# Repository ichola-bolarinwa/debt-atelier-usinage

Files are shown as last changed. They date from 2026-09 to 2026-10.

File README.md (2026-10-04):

# DEBT — Dossier d'exécution BT d'un atelier d'usinage

Projet personnel mené seul par Ichola BOLARINWA, étudiant ingénieur à l'ESIGELEC, dominante Énergie et Développement Durable.

## Objet

Produire, comme le ferait un bureau d'études électricité, le dossier d'exécution de l'installation basse tension d'un atelier d'usinage de PME implanté dans l'agglomération de Rouen : raccordement au réseau public basse tension (segment C4, 36 à 250 kVA), schéma de liaison à la terre TT.

## Nature du projet

Étude de cas fictive. Le site, l'entreprise et le programme de machines sont inventés ; chaque donnée technique provient d'une source réelle citée (fiche constructeur, guide technique, texte réglementaire). Aucun client réel n'est impliqué. Le dossier n'a été vérifié par aucun organisme de contrôle.

## Méthode

Chaque grandeur est calculée à la main, puis vérifiée sous XLPro4 Calcul 400 (Legrand). Les écarts entre calcul manuel et logiciel sont expliqués. Chaque hypothèse de dimensionnement est écrite et justifiée dans le cahier des charges.

## Aperçu : plan d'implantation (en cours)

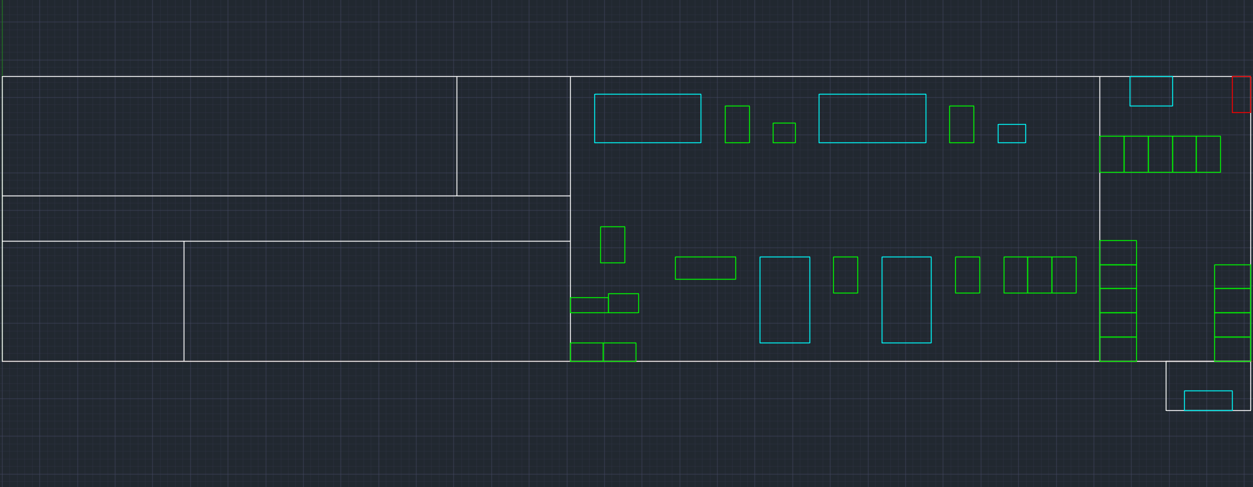
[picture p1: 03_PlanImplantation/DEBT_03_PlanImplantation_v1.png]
Plan d'implantation, état d'avancement


Capture d'avancement du jalon J3.6 : enveloppe du bâtiment, cloisons et implantation des équipements de l'atelier (deux tours CN, deux centres d'usinage, perceuse, postes de préréglage et de contrôle, stockages). Plan non coté, sans échelle ni cartouche ; la version PDF à l'échelle 1:100 remplacera cette image à la clôture du jalon.

Fichier source : [`DEBT_03_PlanImplantation_v1.dwg`](03_PlanImplantation/DEBT_03_PlanImplantation_v1.dwg)

## Livrables

| N° | Livrable | Outil | Dossier | État |
|---|---|---|---|---|
| 00 | Cahier des charges | Claude Docs, export PDF | `00_CahierDesCharges` | Terminé (v1.1) |
| 01 | Bilan de puissance | Excel | `01_BilanPuissance` | Terminé (v4) |
| 02 | Architecture de distribution | Excel, texte | `02_Architecture` | À faire |
| 03 | Plan de masse et d'implantation | AutoCAD | `03_PlanImplantation` | En cours (v1) |
| 04 | Schéma unifilaire | QElectroTech | `04_SchemaUnifilaire` | À faire |
| 05 | Note de calcul manuelle | Excel | `05_NoteCalculManuelle` | À faire |
| 06 | Note de calcul logicielle | XLPro4 Calcul 400 | `06_NoteCalculLogicielle` | À faire |
| 07 | Nomenclature chiffrée | Excel | `07_Nomenclature` | À faire |
| 08 | Synthèse | Texte, export PDF | `08_Synthese` | À faire |

## Avancement

| Jalon | Résultat attendu | État |
|---|---|---|
| J1 | Hypothèses de base validées, cahier des charges v1.0 | Terminé |
| J2 | Machines choisies, bilan de puissance | Terminé |
| J3 | Architecture, plan d'implantation, premier schéma unifilaire | En cours |
| J4 | Note de calcul manuelle complète | À faire |
| J5 | Vérification sous XLPro4 Calcul et analyse des écarts | À faire |
| J6 | Nomenclature chiffrée, synthèse, dossier final | À faire |

## Nommage des fichiers

`DEBT_[NumLivrable]_[Nom]_v[X].[ext]` — exemple : `DEBT_04_SchemaUnifilaire_v2.qet`

## Sources

Voir `SOURCES.md`. Les documents de référence ne sont pas redistribués dans ce dépôt : ils sont protégés par le droit d'auteur de leurs éditeurs.

## Projets liés

Ce dossier est le premier de trois projets. L'avant-projet photovoltaïque (APV) étudiera une centrale en toiture du même bâtiment ; l'outil d'analyse de performance photovoltaïque (MPV) viendra ensuite.

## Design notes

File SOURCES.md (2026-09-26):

# Sources

Documents de référence utilisés pour le DEBT. Titres relevés sur la page de garde ou la page de publication de chaque document. Les documents eux-mêmes ne sont pas redistribués.

## Guides techniques

| Document | Éditeur | Usage |
|---|---|---|
| Guide de l'installation électrique 2017 — Normes internationales CEI et nationales françaises NF | Schneider Electric | Méthodes de calcul : facteurs ku et ks (chapitre A, § 4.3, p. A23 à A26), ratios d'éclairage (fig. A9), schéma TT (chapitre E), sections, chutes de tension, courants de court-circuit, sélectivité |
| NF C 15-100 – Révision 23 août 2024 – Points clés & solutions Legrand, réf. MM224003 (août 2026) | Legrand | Repères généraux d'installation ; orienté logement |
| L'aménagement des bureaux — Principales données ergonomiques, fiche pratique de sécurité ED 23, 2e édition, avril 2007 | INRS | Surface minimale des bureaux : 10 m² utiles par personne, d'après la NF X 35-102 |

## Fiches et catalogues des équipements

| Document | Éditeur | Usage |
|---|---|---|
| Lynx 2100·2600, catalogue, ver. EN 260615 | DN Solutions | Tour Lynx 2100LA : puissance de raccordement 24,21 kVA (p. 32), encombrement (p. 15) |
| DNM 4000, catalogue, ver. EN 260615 | DN Solutions | Centre d'usinage DNM 4000 : puissance de raccordement 29,5 kVA, encombrement (p. 13) |
| Fiche produit OPTIdrill B 34H, article 3020333 | Stürmer Maschinen (Optimum) | Perceuse : moteur 1,50 / 2,20 kW, 400 V |
| OPTIsaw S 275N (revendeurs, source secondaire) | Optimum | Scie : moteur 1,1 kW, pompe 90 W — à confirmer par la fiche du constructeur |
| W22 Three-Phase Electric Motor – Technical Catalogue European Market (50025712) | WEG | Moteurs de référence IE3 : rendement, facteur de puissance, courant (p. 34) |
| Brochure G 2-7 / G 7L-15 / G 15L-22 (2935 0869 42) | Atlas Copco | Compresseur G 11 : 11 kW (p. 7) |
| Manuel d'instructions G 7 / G 11 / G 15 (2924 7191 00) | Atlas Copco | Démarrage étoile-triangle, version IEC (p. 58, 80-81) |
| Technical data / accessories – Demag DC-Com chain hoist (203 571 44, 13/12/2019) | Demag | Palan d'une tonne : moteurs (p. 13, 15, 27, 28), cote de crochet 557 mm (p. 32) |
| Air Conditioning Technical Data RXM-R (EEDEN21A) | Daikin | Pompe à chaleur des bureaux : alimentation, fusible (p. 5-6) |
| Notice technique installation-maintenance JM 12 et JM 22 (19/07/2010) | Jetto | Tubes radiants : 65 W, 230 V (p. 2, 6, 7) |
| Zénéo 200 L vertical mural (revendeurs, source secondaire) | Atlantic | Chauffe-eau : 2 200 W — à confirmer par la fiche du constructeur |

## Tarifs

| Document | Éditeur | Usage |
|---|---|---|
| Tarif professionnel de référence 2026/10 | Legrand | Références et prix de l'appareillage |
| Tarif Legrand Cable Management, juillet 2026 (sans page de garde ; date lue dans l'en-tête de colonne) | Legrand | Références et prix du cheminement des câbles |

## Textes réglementaires

| Document | Éditeur | Usage |
|---|---|---|
| Délibération n° 2025-78 du 13 mars 2025 portant décision sur le tarif d'utilisation des réseaux publics d'électricité dans les domaines de tension HTA et BT (TURPE 7 HTA-BT) | Commission de régulation de l'énergie | Structure et formules du tarif d'acheminement |
| Délibération n° 2026-33 du 4 février 2026 portant modification des tarifs d'utilisation des réseaux publics de distribution et transport d'électricité (TURPE 7 HTA-BT et TURPE 7 HTB) | Commission de régulation de l'énergie | Points techniques du TURPE 7 |
| Délibération n° 2026-105 du 21 mai 2026 portant décision sur l'évolution au 1er août 2026 de la grille tarifaire des tarifs d'utilisation des réseaux publics d'électricité dans les domaines de tension HTA et BT et sur l'évolution du paramètre Rf | Commission de régulation de l'énergie | Coefficients au 1er août 2026 : composante de soutirage (p. 27), dépassements (p. 28), gestion et comptage |
| TURPE 7 HTA/BT – Tarifs en vigueur au 1er août 2026 | Enedis | Formule de la composante de soutirage (p. 15), dépassements (p. 16), saisons tarifaires (p. 22) |

## Limites

La norme NF C 15-100 n'est pas consultée directement : elle est payante. Ses règles sont prises dans les guides des fabricants ci-dessus. La norme EN 15011 (ponts roulants), également payante, n'a pas été consultée.

Les valeurs issues de sources secondaires ou d'hypothèses sont listées dans l'onglet Registre du bilan de puissance, à confirmer avant la version finale du dossier.

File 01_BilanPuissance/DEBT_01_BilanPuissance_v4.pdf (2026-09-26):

Projet DEBT : dossier d'exécution basse tension Bilan de puissance Atelier d'usinage de PME — livrable 1, document de lecture | Référence | DEBT_01
| Version | 4
| Date | 26/09/2026
| Jalon | J2 clos
| Auteur | Ichola BOLARINWA

Ce PDF est une mise en page de lecture du classeur DEBT_01_BilanPuissance_v4.xlsx, qui fait foi : toutes les valeurs y sont calculées par des formules visibles. Méthode : guide Schneider Electric 2017, chapitre A, § 4.3 (p. A22 à A26). Les lignes sur fond clair comportent au moins une valeur à confirmer (section 5).

## 1. Récepteurs

S unitaire : puissance apparente d'un récepteur. Pour une puissance utile de moteur, S = P ⁄ (η × cos φ) ; pour une puissance électrique, S = P ⁄ cos φ ; une puissance donnée en kVA est reprise telle quelle.

Tableau 1 — Récepteurs, puissances et facteurs d'utilisation

Repère | Récepteur et modèle | Groupe | Qté | Donnée constructeur
η | cos
φ

S unitaire
(kVA)

S installée
(kVA)

ku

ku

× S
(kVA)

IB

unitaire
(A)

Statut

T1-T2 Tour à commande numérique DN Solutions Lynx 2100LA
(FANUC)
G1 | 2 | 24,21 kVA | — | — | 24,21 | 48,42 | 0,75 | 36,31 | 34,9 | Sourcé
C1-C2 | Centre d'usinage vertical
DN Solutions DNM 4000
G1 | 2 | 29,50 kVA | — | — | 29,50 | 59,00 | 0,75 | 44,25 | 42,6 | Sourcé
P1 | Perceuse à colonne
Optimum OPTIdrill B 34H (2,2 kW, grande vitesse)
G2 | 1 | 2,20 kW (méca.) | 0,870 | 0,79 | 3,20 | 3,20 | 0,75 | 2,40 | 4,6 | Sourcé

Repère | Récepteur et modèle | Groupe | Qté | Donnée constructeur | η | cos φ | S unitaire (kVA) | S installée (kVA) | ku | ku × S (kVA) | IB unitaire (A) | Statut
S1 | Scie à ruban — moteur de lame Optimum OPTIsaw S 275N | G2 | 1 | 1,10 kW (méca.) | 0,841 | 0,79 | 1,66 | 1,66 | 0,75 | 1,24 | 2,4 | À confirmer
S1p | Scie à ruban — pompe d'arrosage Optimum OPTIsaw S 275N | G2 | 1 | 0,09 kW (élec.) | — | 1,00 | 0,09 | 0,09 | 0,75 | 0,07 | 0,1 | À confirmer
K1 | Compresseur d'air à vis (étoile-triangle) Atlas Copco G 11 | G2 | 1 | 11,00 kW (méca.) | 0,912 | 0,83 | 14,53 | 14,53 | 1,00 | 14,53 | 21,0 | À confirmer
PR-L | Pont roulant 1 t — levage
Demag DC-Com 10, palan à chaîne 1 000 kg, mouflage 1/1
G2 | 1 | 2,15 kVA | — | — | 2,15 | 2,15 | 1,00 | 2,15 | 3,1 | Sourcé
PR-C | Pont roulant 1 t — translation chariot Demag E11 (chariot U11) | G2 | 1 | 0,10 kW (élec.) | — | 1,00 | 0,10 | 0,10 | 1,00 | 0,10 | 0,1 | À confirmer
PR-P | Pont roulant 1 t — translation pont Demag E22-C (2, maître et esclave) | G2 | 2 | 0,20 kW (élec.) | — | 1,00 | 0,20 | 0,40 | 1,00 | 0,40 | 0,3 | À confirmer
E-AT | Éclairage atelier
Luminaires LED
G3 | 1 | 5,60 kVA | — | — | 5,60 | 5,60 | 1,00 | 5,60 | 24,3 | Sourcé
E-MG | Éclairage magasin
Luminaires LED
G3 | 1 | 0,70 kVA | — | — | 0,70 | 0,70 | 1,00 | 0,70 | 3,0 | Sourcé
E-CP | Éclairage local compresseur
Luminaires LED
G3 | 1 | 0,14 kVA | — | — | 0,14 | 0,14 | 1,00 | 0,14 | 0,6 | Sourcé
E-BU | Éclairage bureaux
Luminaires LED
G3 | 1 | 1,44 kVA | — | — | 1,44 | 1,44 | 1,00 | 1,44 | 6,3 | Sourcé
E-LS | Éclairage locaux sociaux
Luminaires LED
G3 | 1 | 0,42 kVA | — | — | 0,42 | 0,42 | 1,00 | 0,42 | 1,8 | Sourcé

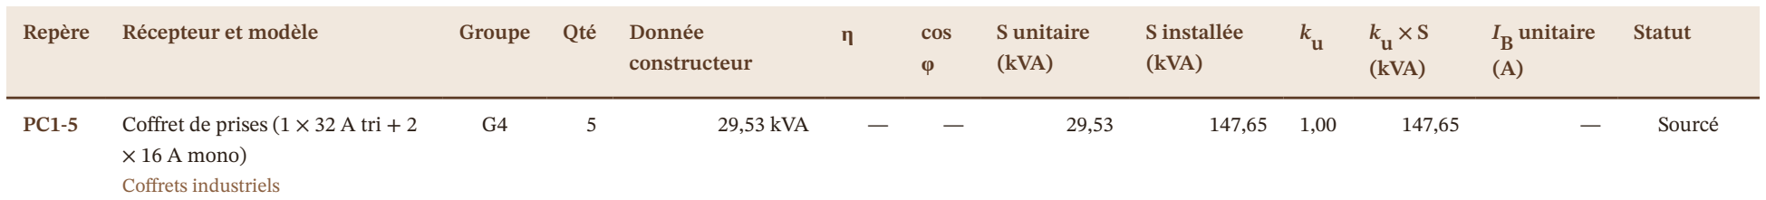
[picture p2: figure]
Repère; Récepteur et modèle; Groupe; Qté; Donnée; constructeur; cos; S unitaire (kVA); S installée (kVA); (kVA); unitaire; Statut; × 16 A mono); Coffrets industriels; 29,53 kVA; Sourcé

PC1-5 | Coffret de prises (1 × 32 A tri + 2
PB | Prises bureautiques
—
G5 | 1 | 1,50 kVA | — | — | 1,50 | 1,50 | 1,00 | 1,50 | 6,5 | Sourcé
CE | Chauffe-eau électrique 200 L
Atlantic Zénéo 200 L vertical mural
G5 | 1 | 2,20 kW (élec.) | — | 1,00 | 2,20 | 2,20 | 1,00 | 2,20 | 9,6 | Sourcé
PAC | Pompe à chaleur air/air bureaux Daikin Perfera FTXM50R + RXM50 | G5 | 1 | 1,45 kW (élec.) | — | 1,00 | 1,45 | 1,45 | 1,00 | 1,45 | 6,3 | À confirmer
TR | Auxiliaires des tubes radiants gaz Jetto Monobloc JM 22 (22 kW gaz) | G5 | 4 | 0,07 kW (élec.) | — | 1,00 | 0,07 | 0,26 | 1,00 | 0,26 | 0,3 | À confirmer
Total | 290,91 | 262,82

## 2. Synthèse par groupe et au TGBT

Tableau 2 — Puissance d'utilisation par groupe : P
u

= k
s

× Σ(ku
× S)
Groupe | Contenu | Σ ku
× S
| | (kVA)

k
s

P
u
(kVA)

IB
(A)

Source du k
s
G1 | Machines à commande numérique (4 circuits) | 80,56 | 0,80 | 64,45 | 93,0 | Fig. A12, p. A25 : tableau de 4 à 5 circuits
G2 | Autres moteurs : perceuse, scie, compresseur, pont roulant (4 circuits) | 20,89 | 0,80 | 16,71 | 24,1 | Fig. A12, p. A25 : tableau de 4 à 5 circuits
G3 | Éclairage | 8,30 | 1,00 | 8,30 | 12,0 | Fig. A13, p. A26 : éclairage
G4 | Coffrets de prises | 147,65 | 0,20 | 29,53 | 42,6 | Fig. A13, p. A26 : prises 0,1 à 0,2, valeur haute (usage industriel)

Groupe | Contenu | Σ ku
× S
| | (kVA)

k
s

P
u
(kVA)

IB
(A)

Source du k
s
G5 | Bureaux, locaux sociaux, chauffage : bureautique, chauffe-eau,
pompe à chaleur, auxiliaires
5,41 | 1,00 | 5,41 | 7,8 | Fig. A13, p. A26 : chauffage et conditionnement d'air ; valeur prudente pour la bureautique

Tableau 3 — Au TGBT

Somme des puissances d'utilisation des groupes | 124,40 kVA

k
s
du TGBT (provisoire, 3 départs supposés ; fig. A12, p. A25) | 0,90
Coefficient d'extension (H13 : aucune extension prévue) | 1,00
Puissance d'utilisation au TGBT | 111,96 kVA
Courant d'emploi au point de livraison | 161,6 A
Marge sous le plafond C4 de 250 kVA | 55,2 %
Contrôle : force motrice d'un atelier d'usinage par ratio (fig. A9, 300 VA/m² × 400 m²) | 120,0 kVA
Contrôle : puissance installée des seules machines à commande numérique | 107,42 kVA

IB =

Pu

3

× U

=

111 963 VA

3

× 400 V

≈ 161,6 A

où P
u

est la puissance d'utilisation au TGBT et U la tension entre phases.

## 3. Puissance à souscrire (TURPE 7, BT > 36 kVA)

Composante de soutirage : CS = b
1

·P
1

+ Σ b
i

·(P
i

− P

i−1) + Σ c
i

·E
i

, avec P
1

≤ P
2

≤ P
3

≤ P
4

et la plage 1 correspondant aux heures pleines de saison haute (Enedis, TURPE 7 HTA/BT au 1er août

2026, p. 15). Le pic de l'atelier tombant en heures pleines toute l'année, les quatre puissances sont égales et seul le terme b 1

·P
1

subsiste.

Tableau 4 — Comparaison des options (coefficients : délibération CRE n° 2026-105, p. 27-28)

Grandeur | Courte utilisation | Longue utilisation
Puissance souscrite, identique sur les quatre plages | 112 kVA | 112 kVA
Énergie annuelle majorante (H12 : 8 h × 5 j × 52 sem., toute en heures pleines) | 232 884 kWh | 232 884 kWh
Composante de soutirage annuelle, cas majorant | 11 916,79 € | 11 979,29 €
Écart longue − courte utilisation | | +62,50 €/an

Conclusion : 112 kVA sur les quatre plages, option courte utilisation. Elle reste la moins chère même dans le cas majorant de H12 ; l'énergie réelle, plus faible, renforce ce choix. Un kVA sous‐ crit en plus coûte 18,15 € par an, une heure de dépassement 12,79 € : une petite marge de souscription vaut mieux que des dépassements.

## 4. Paramètres

Tableau 5 — Surfaces (H5)

Zone | Surface | Source
Atelier | 400 m² | Valeur de programme (H5)
Magasin et expédition | 100 m² | Valeur de programme (H5)
Local compresseur | 20 m² | Valeur de programme (H5)
Bureaux (m² utiles) | 60 m² | INRS ED 23 (2007) : 10 m² par poste × 6 postes (H3, H5)
Locaux sociaux | 60 m² | Valeur de programme (H5)

Tableau 6 — Ratios d'éclairage (H11) et de bureautique

Usage | Ratio | Source
Éclairage — circulation, stockage (150 lx) | 7 VA/m² | Guide Schneider 2017, fig. A9, p. A22-A23 (base fluorescente : majorant pour LED)
Éclairage — gros travaux, atelier (300 lx) | 14 VA/m² | Idem
Éclairage — bureaux (500 lx) | 24 VA/m² | Idem
Force motrice — bureaux (bureautique) | 25 VA/m² | Guide Schneider 2017, fig. A9, p. A23
Contrôle : force motrice atelier d'usinage | 300 VA/m² | Guide Schneider 2017, fig. A9, p. A23 (ordre de grandeur de contrôle)

Coffret de prises type : 1 prise 32 A triphasée et 2 prises 16 A monophasées, soit 29,53 kVA au courant assigné ; 4 coffrets dans l'atelier (un par zone de travail) et 1 au magasin. Calibres normali‐ sés CEI 60309 ; nombre à vérifier sur le plan du J3.

## 5. Sources, justifications et registre

Tableau 7 — Source de chaque donnée et justification du ku

Repère | Source de la donnée | Justification du ku
T1-T2 | Catalogue DN Solutions « Lynx 2100·2600 », ENG E36 260615, p. 32, ligne Power consumption (FANUC). ku : guide Schneider 2017, § 4.3.1, p. A23 | Moteurs en installation industrielle : 0,75 en moyenne (guide Schneider 2017, § 4.3.1, p. A23)
C1-C2 | Catalogue DN Solutions « DNM 4000 », ENG SU E16 260615, p. 13, ligne electric power supply (rated capacity). ku : idem | Idem (§ 4.3.1, p. A23)
P1 | P : fiche Stürmer Maschinen OPTIdrill B 34H, art. 3020333 (1,50 / 2,20 kW, 400 V). η, cos φ : moteur de référence WEG W22 IE3 2,2 kW 4 pôles, carcasse 100L, catalogue WEG 50025712, p. 34 (In = 4,62 A) | Idem (§ 4.3.1, p. A23) ; machine manuelle intermittente
S1 | P : Optimum S 275N, 1,1 kW 400 V (revendeurs : source secondaire). η, cos φ : moteur de référence WEG W22 IE3 1,1 kW 4 pôles, carcasse 90S, catalogue WEG 50025712, p. 34 (In = 2,39 A) | Idem (§ 4.3.1, p. A23)
S1p | P : fiche Optimum S 275N (90 W). cos φ inconnu, pris égal à 1 (sous-estimation négligeable) | Idem (§ 4.3.1, p. A23)

Repère | Source de la donnée | Justification du ku
K1 | P = 11 kW : brochure Atlas Copco G 2-22 (2935 0869 42), p. 7. Démarrage étoile-triangle (version IEC) : manuel Atlas Copco G 7-G 15 (2924 7191 00), p. 58 et 80-81. η, cos φ : moteur de référence WEG W22 IE3 11 kW 2 pôles, catalogue WEG 50025712,
p. 34 (In = 21,0 A). Polarité réelle à lire sur plaque
| | Au-dessus de la moyenne du § 4.3.1 : fonctionnement quasi continu pendant le poste ; 1 retenu par prudence
PR-L | Moteur ZNK 100 A 8/2, grande vitesse 1,10 kW, 40 % ED, In = 3,1 A à 380-415 V, cos φ 0,81 : Demag, Technical data DC-Com (203 571 44, 13/12/2019), p. 13 et 15. S = √3 × 400 × 3,1 | Moteur à pleine charge pendant le levage ; l'intermittence est prise en compte par le ks du groupe
PR-C | Demag 203 571 44, p. 27 : E11, 0,1 / 0,025 kW. cos φ inconnu : S pris égal à P (sous-estimation négligeable) | Idem levage
PR-P | Hypothèse : 2 motoréducteurs E22-C, 0,2 / 0,05 kW, cités comme entraînement de translation (Demag 203 571 44, p. 28). À confirmer par devis de pont | Idem levage
E-AT | Surface H5 × ratio fig. A9 (300 lx). ku = 1 : guide Schneider, p. A23 | Éclairage : ku = 1 (§ 4.3.1, p. A23)
E-MG | Surface H5 × ratio fig. A9 (150 lx) | Idem
E-CP | Surface H5 × ratio fig. A9 (150 lx) | Idem
E-BU | Surface H5 × ratio fig. A9 (500 lx) | Idem
E-LS | Surface H5 × ratio fig. A9, ligne circulation (choix : pas de ligne spécifique) | Idem
PC1-5 | Choix de conception (4 coffrets atelier, 1 magasin), méthode du courant assigné. ks du groupe : fig. A13 | Prises comptées à leur courant assigné (ku = 1) ; la faible utilisation est prise par ks = 0,2 (fig. A13, p. A26)
PB | Surface bureaux × ratio fig. A9 « bureaux » (25 VA/m²) | Ratio de consommation déjà moyenné (fig. A9) : pas de réduction supplémentaire
CE | Fiche Atlantic Zénéo, réf. ED 999 538 (octobre 2015) : 2 200 W, 230 V. Résistif : cos φ = 1, ku = 1 (p. A23) | Résistif, chauffage : ku = 1 (§ 4.3.1, p. A23)
PAC | daikin.eu : capacité de chauffage nominale 5,8 kW, COP 4,00, d'où P = 5,8 ⁄ 4,00. Non dimensionnée par calcul thermique ; cos φ pris égal à 1. À confirmer : puissance absorbée maximale | Chauffage et climatisation : ku = 1 (§ 4.3.1 ; fig. A13)
TR | Fiche Jetto Monobloc (Batiproduits) : 65 W, 230 V. Nombre de tubes provisoire (4) : calcul de déperditions au J6. Impact négligeable | Auxiliaires en service pendant toute la chauffe : ku = 1

Tableau 8 — Registre des sources à confirmer avant la version finale

N° | Élément | Valeur provisoire | Source actuelle | Source à obtenir | Poids sur le bilan
1 | Scie : fiche constructeur | 1,1 kW ; pompe 90 W | Revendeurs Optimum (secondaire) | Fiche ou notice Optimum / Stürmer S 275N (réf. 3300260) | Négligeable

### 2 Compresseur : polarité et courant du

moteur

2 pôles supposés ; 21,0 A
(moteur de référence)

WEG W22 IE3 11 kW 2 p. (primaire, moteur de référence)

Plaque signalétique ou fiche électrique Atlas Copco G 11

Modéré (≈ 14 kVA)

3 | Pont roulant : translation du pont | 2 × 0,2 kW | Demag 203 571 44, p. 28 (usage hors palan)
Devis d'un pont monopoutre 1 t | Négligeable

4 Pont roulant : hauteur de poutre,
chemin de roulement, jeu en partie haute
à déterminer | — | Devis constructeur ; norme EN 15011 (payante)

Conditionne la hauteur
sous charpente (H4)

### 5 Pompe à chaleur : puissance absorbée

maximale

1,45 kW (nominale) ;
fusible maxi 16 A

daikin.eu ; fiche RXM-R
(EEDEN21A), p. 5-6
Pages FTXM50R du databook Daikin | Faible
6 | Tubes radiants : nombre | 4 × 65 W | Notice Jetto JM 12 / JM 22 (19/07/2010), p. 2, 6, 7
Calcul de déperditions (J6) | Négligeable
7 | Tubes radiants : tension neutre-terre | aucune tension admise (notice Jetto) | Notice Jetto, p. 7 | Vérification en schéma TT au J4 ; transformateur de séparation éventuel | Point de protection, pas de puissance
8 | Chauffe-eau : fiche chiffrée | 2 200 W | Revendeurs (secondaire) | Fiche Atlantic Zénéo en vigueur | Négligeable

### 9 Coffrets de prises : nombre et

| composition | 5 coffrets (1 × 32 A tri + 2 × 16 A) | Choix de conception (onglet Paramètres) | Vérification sur le plan AutoCAD (J3) | Fort (≈ 30 kVA d'utilisation)
10 | ks du TGBT | 0,9 (3 départs supposés) | Fig. A12, hypothèse d'architecture | Architecture de distribution (J3) | Modéré (≈ 12 kVA)

### 11 TURPE : puissance souscrite minimale

| et maximale, heures creuses | — | Brochure Enedis au 01/08/2026 (souscription par multiples de 1 kVA) | Délibération CRE 2025-78, § 5.1, p. 140-146 | Faible sur le choix
DEBT_01_BilanPuissance, version 4 | Étude de cas fictive, projet personnel

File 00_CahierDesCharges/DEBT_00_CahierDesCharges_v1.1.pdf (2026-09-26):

Projet DEBT : dossier d'exécution basse tension Cahier des charges Installation électrique d'un atelier d'usinage de PME | Référence | DEBT_00
| Version | 1.1
| Date | 26/09/2026
| Jalon | J2 clos
| Auteur | Ichola BOLARINWA

## Historique des versions

Version | Date | Modifications
1.1 | 26/09/2026 | Clôture du jalon J2 : bilan de puissance (DEBT_01, version 4), puissance souscrite de 112 kVA en courte utilisation ; H11 validée, H12 et H13 ajoutées ; cote de crochet du pont roulant ; référentiel documentaire complété ; registre des sources à confirmer tenu dans le bilan.
1.0 | 22/09/2026 | Clôture du jalon J1 : hypothèses de base H1 à H5, H7 et H8 validées et justifiées ; relecture de cohérence intégrée. Restent H11 (J2), H10 (J3), H6 (J4) et H9 (J5).
0.5 | 20/09/2026 | Jalon J1 en cours : H1 à H5, H7 et H8 validées (condition de desserte gaz ajoutée à H1) ; relecture de cohérence ; titres du référentiel documentaire vérifiés sur les pages de garde, noms de fichiers corrigés.
0.4 | 20/09/2026 | Ajout du plan de masse et d'implantation sous AutoCAD (livrable 3).
0.3 | 20/09/2026 | Recentrage sur le besoin : notes de publication et d'outillage retirées, historique placé en tête.
0.2 | 20/09/2026 | Référentiel documentaire aligné sur les fichiers réels ; validation des hypothèses par jalon.
0.1 | 20/09/2026 | Brouillon initial.

## 1. Contexte et objectif

Le projet produit, comme le ferait un bureau d'études électricité, le dossier d'exécution de l'installation basse ten‐ sion d'un atelier d'usinage de PME.

C'est un projet personnel, sous forme d'étude de cas fictive. Le site, l'entreprise et le programme de machines sont inventés, mais chaque donnée technique vient d'une source réelle : fiche constructeur, guide technique ou texte ré‐ glementaire. Aucun client réel n'est impliqué.

Le DEBT est le premier de trois projets liés. L'avant-projet photovoltaïque (APV) étudiera ensuite une centrale en toiture de ce même bâtiment. L'outil d'analyse de performance (MPV) viendra en dernier.

Ce document est en version 1.1, qui clôt le jalon J2 ; l'historique en tête retrace son évolution. Chaque hypothèse est repérée par un code (H1, H2…) et validée au jalon où elle devient nécessaire (section 11).

## 2. Description du site

Le site est un atelier d'usinage de mécanique générale de 12 salariés travaillant en un poste de journée, 5 jours sur 7, qui réalise des pièces unitaires et de petites séries en sous-traitance (H2, H3).

Justification de l'effectif (H3). La répartition découle d'un raisonnement poste par poste sur le parc de production (H7), sans ratio normatif : 6 personnes en production (4 opérateurs-régleurs, un par machine à commande nu‐ mérique ; 1 opérateur pour le débit et les reprises ; 1 chef d'atelier, qui conduit aussi le pont roulant), 3 en sup‐ port technique (méthodes et programmation, qualité et contrôle, magasin) et 3 en administration (dirigeant, chargé d'affaires, administration et comptabilité). Six personnes occupent un poste de bureau : les trois adminis‐ tratifs, les techniciens méthodes et qualité, et le chef d'atelier dans un bureau d'atelier. Seuls ces six postes entrent dans le dimensionnement des bureaux (H5) ; l'effectif total dimensionne les locaux sociaux. Le travail en un poste de journée place la consommation aux heures de production photovoltaïque, ce qui sert l'APV.

Il est implanté dans l'agglomération de Rouen (H1), sur un site desservi par le réseau de gaz naturel. Ce choix sert aussi l'APV, qui aura besoin de données d'ensoleillement réelles pour ce lieu.

Le bâtiment est de plain-pied, à ossature en portiques acier, couvert d'une toiture en bac acier double peau isolée (H4). Les charges des machines-outils imposent une implantation sur dallage ; les portiques acier dégagent des portées libres et portent le chemin de roulement du pont roulant ; la toiture isolée est la condition d'un atelier chauffé et reste compatible avec la centrale photovoltaïque de l'APV. La charpente métallique est un élément conducteur étranger au sens du guide Schneider (chapitre E, § 1.1, p. E2) : elle sera reliée à la liaison équipoten‐ tielle principale. La hauteur sous charpente sera fixée au jalon J3, avec le plan : elle cumule la hauteur utile sous crochet, la cote de crochet du palan retenu (557 mm pour le Demag DC-Com 10 sur chariot U11, fiche Demag 203 571 44, p. 32), la hauteur de la poutre et du chemin de roulement, et un jeu de sécurité en partie haute (norme EN 15011).

Tableau 1 — Surfaces des zones (H5)

Zone | Surface provisoire | Origine | Vérification
Atelier de production | 400 m² | Valeur de programme (maître d'ouvrage) | J3 : emprises des machines (fiches J2) et allées sur le plan
Local compresseur | 20 m² | Valeur de programme | J2 : encombrement et dégagements de maintenance de la fiche constructeur
Magasin et expédition | 100 m² | Valeur de programme | J3, sur le plan

Zone | Surface provisoire | Origine | Vérification
Bureaux | 60 m² utiles minimum | INRS ED 23 (2007), relayant la NF X 35-102 : 10 m² utiles par personne | J3 : salle de réunion, accueil et circulations dessinés sur le plan

Locaux
sociaux
60 m² | Valeur de programme | J3 : équipements exigés par le Code du travail (art. R4228-1 et suivants) selon l'effectif

Justification des surfaces (H5). Aucune norme ne donne de surface d'atelier par machine : la surface de l'atelier se détermine géométriquement, par l'emprise des machines, leurs zones de travail et de maintenance et les al‐ lées. Faute de ces données au jalon J1, les surfaces de l'atelier, du local compresseur, du magasin et des locaux sociaux sont des valeurs de programme, fixées par le maître d'ouvrage et vérifiées aux jalons indiqués ; elles sont révisées si le plan les contredit.

Seule la surface des bureaux est sourcée : la fiche INRS ED 23 recommande 10 m² utiles par personne, circula‐ tions et autres locaux exclus. Avec les six postes de bureau retenus en H3 :

### Sbureaux = n × s = 6 × 10 m² = 60 m²

où n est le nombre de postes de bureau (H3) et s la surface utile minimale par personne (INRS ED 23).

Limite : cette fiche date de 2007 et relaie une édition antérieure de la NF X 35-102, non consultée directement. Le bilan de puissance du jalon J2 utilise ces surfaces provisoires pour l'éclairage ; il est corrigé au J3.

L'emprise totale, hors annexes des bureaux, fixe aussi la toiture disponible pour l'APV :

### Stotale = 400 + 20 + 100 + 60 + 60 = 640 m²

Les surfaces fixent l'éclairage et le nombre de prises ; elles sont provisoires jusqu'au plan du J3 (H5).

## 3. Alimentation et raccordement

L'atelier est raccordé au réseau public basse tension d'Enedis, avec une puissance comprise entre 36 et 250 kVA : c'est le segment C4, anciennement appelé « tarif jaune ».

Réseau | Triphasé 230/400 V avec neutre, 50 Hz.
Schéma de liaison à la terre | TT. Il est obligatoire pour une installation alimentée directe‐ ment par le réseau public basse tension (guide Schneider, cha‐

pitre E, note [p] du tableau de choix des schémas de liaison à la terre, p. E13).

Puissance souscrite | 112 kVA sur les quatre plages temporelles, option courte utili‐ sation (bilan DEBT_01, onglet Souscription ; formules du TURPE 7, délibération CRE n° 2025-78 ; coefficients au 1er août
| 2026, délibération n° 2026-105).
Courant de court-circuit au point de livraison | Valeur à fixer et à sourcer avant les calculs (H6).

Le bilan de puissance doit rester sous 250 kVA. En triphasé équilibré, le courant de ligne correspondant vaut :

I =

S

3

× U

=

250 000 VA

3

× 400 V

≈ 360,8 A

où S est la puissance apparente (en voltampères), U la tension entre phases (en volts) et I le courant de ligne (en ampères) ;
soit environ 361 A.

Au-delà de 250 kVA, il faudrait un poste de transformation HTA/BT, hors du périmètre du projet.

Le tableau général basse tension (TGBT) prévoit une réserve pour raccorder plus tard la centrale photovoltaïque de l'APV.

## 4. Récepteurs à alimenter

Le programme compte huit machines de production et utilités motorisées, validées en H7, plus l'éclairage, les prises et le chauffage. Chaque puissance sera prise sur la fiche technique d'un modèle réel, choisi et cité avec sa ré‐ férence exacte.

Tableau 2 — Récepteurs (H7, H8)

Récepteur | Quantité | Type de charge | Zone
Tour à commande numérique | 2 | Moteurs sur variateurs | Atelier
Centre d'usinage vertical | 2 | Moteurs sur variateurs | Atelier
Perceuse à colonne | 1 | Moteur, démarrage direct | Atelier
Scie à ruban | 1 | Moteur, démarrage direct | Atelier
Compresseur d'air à vis | 1 | Moteur, démarrage étoile-triangle (vitesse fixe) | Local compresseur
Pont roulant | 1 | Moteurs de levage et de translation | Atelier

Récepteur | Quantité | Type de charge | Zone
Éclairage à LED | — | Éclairage | Toutes zones
Prises de courant 16 A et prises industrielles 32 A | — | Prises | Atelier, magasin
Prises bureautiques | — | Prises | Bureaux
Pompe à chaleur air/air | 1 | Moteur de compresseur | Bureaux
Chauffe-eau électrique | 1 | Résistif | Locaux sociaux
Chauffage de l'atelier | — | Tubes radiants gaz : auxiliaires électriques seuls | Atelier

Justification du parc de production (H7). La liste contient une fois chacun des trois modes d'alimentation d'un moteur : démarrage direct (perceuse, scie), démarrage étoile-triangle (compresseur) et variateur de vitesse (tours et centres d'usinage). Chaque mode se traite différemment à la note de calcul, pour la chute de tension au dé‐ marrage comme pour le réglage des protections. Les variateurs introduisent en outre des courants harmoniques (guide Schneider, chapitre M) et des courants de fuite à la terre qui conditionnent le choix des dispositifs diffé‐ rentiels en schéma TT (chapitre F). La liste couvre enfin les deux services extrêmes, continu pour le compres‐ seur et intermittent pour le pont roulant. Les quantités sont un choix de scénario, non tiré d'une source : elles doivent rester cohérentes avec l'effectif (H3). Les accessoires des machines à commande numérique (arrosage, convoyeur à copeaux, groupe hydraulique) sont compris dans la puissance globale donnée par le constructeur.

Justification du chauffage de l'atelier (H8). Dans un grand volume haut, l'air chaud s'accumule sous la toiture (stratification) : chauffer l'air chauffe surtout le haut du bâtiment. Le chauffage par rayonnement, qui chauffe directement les personnes, les machines et le sol, est donc retenu. Parmi les solutions rayonnantes, les tubes ra‐ diants gaz maintiennent le bilan électrique centré sur les machines : seuls leurs auxiliaires (extracteurs de fu‐ mées, allumage, régulation) sont alimentés, avec des puissances lues sur la fiche du modèle retenu au jalon J2. Leur hauteur minimale de pose devra rester compatible avec la hauteur sous charpente et le passage du pont roulant (vérification au J3). Le gaz impose un site desservi par le réseau de gaz naturel, condition ajoutée à H1. Une variante par panneaux radiants électriques sera chiffrée au J6 sur la base d'un calcul de déperditions (isola‐ tion des parois, volume, température extérieure de base), pour évaluer son effet sur le bilan de puissance et sur le plafond de 250 kVA du raccordement C4.

Les bornes de recharge de véhicules électriques restent hors périmètre.

### Bilan de puissance (jalon J2)

Le bilan de puissance est tenu dans le fichier DEBT_01_BilanPuissance (livrable 1). Il suit la méthode du guide Schneider 2017, chapitre A, § 4.3 : chaque récepteur reçoit un facteur d'utilisation k
u

(0,75 pour les moteurs ; 1 pour l'éclairage, le chauffage et le compresseur, en fonctionnement quasi continu), puis chaque groupe un facteur de si‐ multanéité k
s

(figures A12 et A13, p. A25-A26). Chaque coefficient est justifié ligne par ligne dans le fichier.

Tableau 3 — Résultats du bilan de puissance (version 4)

Grandeur | Valeur | Origine
Puissance installée | 290,9 kVA | Somme des puissances des récepteurs
Puissance d'utilisation au TGBT | 112,0 kVA | Coefficients k u et k s , extension nulle (H13)
Courant d'emploi au point de livraison | 161,6 A | Calcul ci-dessous
Marge sous le plafond C4 | 55 % | Plafond de 250 kVA
Puissance souscrite | 112 kVA | Quatre plages égales, courte utilisation (H12)

IB =

Pu

3

× U

=

111 960 VA

3

× 400 V

≈ 161,6 A

où P
u

est la puissance d'utilisation au TGBT (en voltampères) et U la tension entre phases (en volts).

La puissance installée dépasse le plafond de 250 kVA, mais c'est la puissance d'utilisation qui se souscrit : l'écart tient surtout aux coffrets de prises, comptés à leur courant assigné puis réduits par k
s

= 0,2.

Modèles retenus : DN Solutions Lynx 2100LA (tours, 24,21 kVA), DN Solutions DNM 4000 (centres d'usinage, 29,5 kVA), Optimum OPTIdrill B 34H (perceuse, 2,2 kW), Optimum OPTIsaw S 275N (scie, 1,1 kW), Atlas Copco G 11 (compresseur, 11 kW, démarrage étoile-triangle), Demag DC-Com 10 (palan d'une tonne du pont roulant). Le ren‐ dement et le facteur de puissance des moteurs dont le constructeur ne publie pas ces valeurs sont pris sur un mo‐ teur de référence WEG W22 IE3 de même puissance et même polarité.

Les valeurs issues de sources secondaires ou d'hypothèses sont inscrites au registre des sources à confirmer (onglet Registre du bilan), à vider avant la version finale du dossier.

## 5. Livrables

Le dossier final comprend huit livrables, publiés ensemble.

Bilan de puissance (tableur) : puissance installée par récepteur, coefficients d'utilisation et de simultanéité, puissance d'utilisation, puissance souscrite recommandée.

Architecture de distribution : tableau général basse tension et tableaux divisionnaires (atelier, bureaux, utili‐ tés), avec la justification du découpage.

Plan de masse et d'implantation, réalisé sous AutoCAD : position des tableaux et des récepteurs, chemine‐ ment des câbles. Il fournit les longueurs de câbles de la note de calcul.

Schéma unifilaire du tableau général et des tableaux divisionnaires, réalisé sous QElectroTech.

1.

2.

3.

4.

Note de calcul manuelle, pour chaque départ :

courant d'emploi et section des câbles selon le mode de pose ;

chute de tension en régime normal et au démarrage des moteurs ;

courants de court-circuit maximal et minimal ;

choix des protections : calibre, pouvoir de coupure, courbe de déclenchement ;

protection des personnes en schéma TT : dispositifs différentiels et prise de terre ;

sélectivité entre les protections.

Note de calcul logicielle sous XLPro4 Calcul, avec un tableau comparatif des écarts par rapport au calcul ma‐ nuel.

Nomenclature chiffrée du matériel, avec références exactes et prix du tarif Legrand.

Synthèse : choix retenus, limites de l'étude, points à approfondir.

## 6. Méthodologie

Chaque grandeur est d'abord calculée à la main, puis vérifiée avec le logiciel. Le logiciel contrôle le calcul, il ne le remplace pas. Les étapes s'enchaînent dans cet ordre :

1
Hypothèses validées

2
Bilan de puissance

3
Architecture

4
Calcul manuel

5
Vérification sous XL‐
Pro4 Calcul

6
Analyse des écarts

7
Unifilaire et nomen‐
clature

8
Synthèse

Deux règles s'appliquent à toutes les étapes. Chaque valeur cite sa source (tableau du guide, page de la fiche tech‐ nique). Tout écart de plus de 5 % entre calcul manuel et logiciel est expliqué (H9).

## 7. Référentiel documentaire

Chaque document est cité par son titre et son éditeur, avec le nom exact du fichier dans le dossier du projet. Les titres ont été vérifiés sur la page de garde de chaque document le 20/09/2026.

Tableau 4 — Documents de référence

Document | Fichier | Usage dans le DEBT
Guide de l'installation électrique 2017 — Normes internationales CEI et nationales françaises NF, Schneider Electric | Guide_de_l_installa tion_électrique_Sch neider.pdf | Méthodes de calcul : coefficients du bilan, sections, chutes de tension, courts-circuits, sélectivité

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
Document | Fichier | Usage dans le DEBT
NF C 15-100 – Révision 23 août 2024 – Points clés & solutions Legrand, réf. MM224003 (août 2026), Legrand | legrand-guide-norme- nf-c-15-100.pdf | Mémo d'installation orienté logement (23 pages) : repères généraux seulement. Ne traite ni le schéma TT ni les chutes de tension, portés par le guide Schneider. Pages citées en numérotation imprimée (deux pages imprimées par page du fichier)
Tarif professionnel de référence 2026/10, Legrand | legrand-tarif- professionnel- reference- ht_Octobre_2026.xlsx | Références et prix de l'appareillage

Tarif Legrand Cable Management, juillet 2026 (sans page de garde : date lue dans l'en-tête de colonne « Tarif Juillet 2026 »)

tarif-lcm-legrandcablemanagement_Juillet_2
026.xlsx

Références et prix du cheminement des câbles

Délibération CRE n° 2026-33 du 4 février 2026 portant modification des tarifs d'utilisation des réseaux publics de distribution et transport d'électricité (TURPE 7 HTA-BT et TURPE 7 HTB)

260204_2026-33_Modi
f_TURPE_7_HTB_HTA_BT
.pdf

Points techniques du TURPE 7 (heures creuses méridiennes, zones injection/ soutirage) ; usage limité

Délibération CRE n° 2026-105 du 21 mai 2026 portant décision sur l'évolution au 1er août 2026 de la

grille tarifaire des tarifs d'utilisation des réseaux publics d'électricité dans les domaines de tension HTA et BT et sur l'évolution du paramètre Rf

260521_2026-105_Evo
lution_TURPE_7_HTA-BT.pdf

Tarif d'acheminement, choix de la puissance souscrite

L'aménagement des bureaux — Principales données ergonomiques, fiche pratique de sécurité ED 23, 2e

édition, avril 2007, INRS

Consultée en ligne, non
téléversée

Surface minimale des bureaux : 10 m² utiles par personne, d'après la NF X 35-102 (p. 1)

Fiches techniques des machines retenues

Détail dans le bilan
DEBT_01 (colonne
Source) et dans
SOURCES.md

Puissances, courants et modes de démarrage des récepteurs

Lynx 2100·2600, catalogue, ver. EN 260615, DN Solutions

ENG_Lynx_2100_2600_
series_E36_260615.p
df

Puissance de raccordement du tour Lynx 2100LA : 24,21 kVA (p. 32) ; encombrement (p. 15)

Document | Fichier | Usage dans le DEBT
DNM 4000, catalogue, ver. EN 260615, DN Solutions | ENG_DNM_4000_SU_E16_ 260615.pdf | Puissance de raccordement du centre DNM 4000 : 29,5 kVA ; encombrement
(p. 13)
W22 Three-Phase Electric Motor – Technical Catalogue European Market (50025712), WEG | Consulté en ligne (weg.net) | Rendement, facteur de puissance et courant des moteurs de référence IE3
(p. 34)
Technical data / accessories – Demag DC-Com chain hoist (203 571 44, 13/12/2019), Demag | Consulté en ligne (demagcranes.com) | Moteurs du palan de 1 t (p. 13, 15, 27,
28) ; cote de crochet (p. 32)

Brochure G 2-7 / G 7L-15 / G 15L-22 (2935 0869 42) et manuel
d'instructions G 7-G 11-G 15 (2924 7191 00), Atlas Copco
Consultés en ligne | Puissance du compresseur G 11 (brochure, p. 7) ; démarrage étoile- triangle (manuel, p. 58 et 80-81)

Délibération CRE n° 2025-78 du 13 mars 2025 portant décision sur le tarif d'utilisation des réseaux publics d'électricité dans les domaines de tension HTA et BT (TURPE 7 HTA-BT)

Consultée en ligne
(cre.fr)

Structure et formules du tarif d'acheminement

TURPE 7 HTA/BT – Tarifs en vigueur au 1er août 2026, Enedis

Consultée en ligne
(enedis.fr)

Formule de la composante de soutirage
(p. 15), dépassements (p. 16), saisons
(p. 22)

## 8. Outils

Cinq outils couvrent le projet.

Tableau 5 — Outils et rôles

Outil | Rôle
Tableur (Excel) | Bilan de puissance et calculs manuels, formules visibles
AutoCAD | Plan de masse et d'implantation, longueurs de câbles
QElectroTech | Schéma unifilaire
XLPro4 Calcul 400, Legrand | Vérification de la note de calcul
Git et GitHub | Historique des versions et publication du dossier

## 9. Contraintes, limites et critères de réussite

Le dossier est réussi si un technicien qui ne connaît pas le projet peut refaire chaque calcul à partir des sources ci‐ tées.

### Contraintes

Puissance totale sous 250 kVA, pour rester en raccordement basse tension.

Matériel de distribution d'un seul fabricant (Legrand), cohérent avec XLPro4 Calcul et le tarif utilisé.

Schéma de liaison à la terre TT.

### Limites assumées

La norme NF C 15-100 n'est pas consultée directement : elle est payante. Ses règles sont prises dans les guides des fabricants.

Les longueurs de câbles viennent d'un plan de masse simplifié, tracé sous AutoCAD (H10).

La puissance d'éclairage est estimée par un ratio en W/m², sans étude d'éclairement (H11).

Les harmoniques dues aux variateurs sont identifiées (H7) mais pas quantifiées : ni calcul du taux de distorsion, ni dimensionnement de filtres.

Le dossier n'est vérifié par aucun organisme de contrôle.

### Critères de réussite

Chaque valeur du dossier cite sa source.

Chaque départ est calculé à la main et vérifié au logiciel.

Chaque écart de plus de 5 % est expliqué.

Le dossier complet est publié sur GitHub.

## 10. Jalons et publication

Le projet avance en six jalons, sans date fixée pour l'instant. Chaque jalon terminé est envoyé sur GitHub. Le cahier des charges évolue avec eux : chaque version est exportée en PDF et remplace la précédente, et l'historique de Gi‐ tHub les conserve toutes.

Tableau 6 — Jalons

Jalon | Résultat | État
J1 | Hypothèses de base validées (H1 à H5, H7, H8), cahier des charges en version 1.0 | ✓ Clos
J2 | Machines choisies, bilan de puissance et puissance souscrite (H11 à H13) | ✓ Clos
J3 | Architecture de distribution, plan d'implantation et premier schéma unifilaire | À venir

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
Jalon | Résultat | État
J4 | Note de calcul manuelle complète | À venir
J5 | Vérification sous XLPro4 Calcul et analyse des écarts | À venir
J6 | Nomenclature chiffrée, synthèse et dossier final publié | À venir

## 11. Hypothèses

Dix hypothèses sont validées à ce stade : H1 à H5, H7 et H8 au jalon J1 ; H11 (éclairage), H12 (fonctionnement) et H13 (extension) au jalon J2. Restent H10 au J3, H6 au J4 et H9 au J5.

Tableau 7 — Registre des hypothèses

Code | Hypothèse | Statut
H1 | Implantation dans l'agglomération de Rouen, sur un site desservi par le réseau de gaz naturel (condition de H8) | ✓ Validée
H2 | Activité d'usinage de mécanique générale | ✓ Validée
H3 | Effectif de 12 salariés en un poste de journée, 5 jours sur 7 ; 6 postes de bureau | ✓ Validée
H4 | Bâtiment de plain-pied, ossature en portiques acier, toiture en bac acier double peau isolée ; hauteur sous charpente fixée au J3 (cote de crochet de 557 mm, Demag DC- Com 10) | ✓ Validée
H5 | Surfaces des zones (section 2) : atelier 400 m², compresseur 20 m², magasin 100 m², locaux sociaux 60 m² en valeurs de programme ; bureaux 60 m² utiles minimum (INRS ED 23) ; vérification aux J2 et J3

✓ Validée

H6 | Courant de court-circuit au point de livraison, valeur à sourcer | À valider (J4)
H7 | Parc de production (section 4) : 2 tours à commande numérique et 2 centres d'usinage verticaux sur variateurs, 1 perceuse à colonne et 1 scie à ruban en démarrage direct, 1 compresseur à vis à vitesse fixe en démarrage étoile-triangle, 1 pont roulant ; modèles et puissances choisis au J2 | ✓ Validée
H8 | Chauffage de l'atelier par tubes radiants gaz ; seuls les auxiliaires électriques (extracteurs, allumage, régulation) entrent au bilan ; variante électrique (panneaux radiants) chiffrée au J6

✓ Validée

H9 | Seuil d'écart accepté entre calcul manuel et logiciel : 5 % | À valider (J5)
H10 | Longueurs de câbles issues d'un plan de masse simplifié | À valider (J3)

Code | Hypothèse | Statut
H11 | Puissance d'éclairage estimée par ratio (guide Schneider, fig. A9) : 7 VA/m² en circulation et stockage, 14 VA/m² en atelier, 24 VA/m² en bureaux ; ratios établis pour le fluorescent, donc majorants pour des luminaires LED | ✓ Validée
H12 | Fonctionnement pour le choix de l'option tarifaire : 8 h par jour, 5 jours par semaine, 52 semaines par an, à la puissance d'utilisation, toute l'énergie en heures pleines. Majorant volontaire : il favorise la longue utilisation, qui reste pourtant plus chère

✓ Validée

H13 Aucune extension prévue de l'installation : coefficient d'extension égal à 1. La marge de 55 % sous le plafond C4 absorberait une extension modérée sans changer de raccordement

✓ Validée

DEBT_00_CahierDesCharges, version 1.1 | Étude de cas fictive, projet personnel

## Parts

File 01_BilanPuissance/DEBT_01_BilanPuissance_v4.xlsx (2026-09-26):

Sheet: Bilan
DEBT_01 — Bilan de puissance — Récepteurs
Unités de la donnée : kVA = puissance apparente constructeur ; kWm = puissance utile mécanique d'un moteur (S = P ⁄ (η × cos φ)) ; kWe = puissance électrique absorbée (S = P ⁄ cos φ)
Repère | Récepteur | Modèle retenu | Groupe | Qté | Tension (V) | Donnée constructeur | Unité | η | cos φ | S unitaire (kVA) | S installée (kVA) | ku | ku × S (kVA) | IB unitaire (A) | Source de la donnée | Statut | Justification du ku
T1-T2 | Tour à commande numérique | DN Solutions Lynx 2100LA (FANUC) | G1 | 2 | 400 | 24.21 | kVA |  |  | 24.21 | 48.42 | 0.75 | 36.31 | 34.9 | Catalogue DN Solutions « Lynx 2100·2600 », ENG E36 260615, p. 32, ligne Power consumption (FANUC). ku : guide Schneider 2017, § 4.3.1, p. A23 | Sourcé | Moteurs en installation industrielle : 0,75 en moyenne (guide Schneider 2017, § 4.3.1, p. A23)
C1-C2 | Centre d'usinage vertical | DN Solutions DNM 4000 | G1 | 2 | 400 | 29.50 | kVA |  |  | 29.50 | 59.00 | 0.75 | 44.25 | 42.6 | Catalogue DN Solutions « DNM 4000 », ENG SU E16 260615, p. 13, ligne electric power supply (rated capacity). ku : idem | Sourcé | Idem (§ 4.3.1, p. A23)
P1 | Perceuse à colonne | Optimum OPTIdrill B 34H (2,2 kW, grande vitesse) | G2 | 1 | 400 | 2.20 | kWm | 0.870 | 0.790 | 3.20 | 3.20 | 0.75 | 2.40 | 4.6 | P : fiche Stürmer Maschinen OPTIdrill B 34H, art. 3020333 (1,50 / 2,20 kW, 400 V). η, cos φ : moteur de référence WEG W22 IE3 2,2 kW 4 pôles, carcasse 100L, catalogue WEG 50025712, p. 34 (In = 4,62 A) | Sourcé | Idem (§ 4.3.1, p. A23) ; machine manuelle intermittente
S1 | Scie à ruban — moteur de lame | Optimum OPTIsaw S 275N | G2 | 1 | 400 | 1.10 | kWm | 0.841 | 0.790 | 1.66 | 1.66 | 0.75 | 1.24 | 2.4 | P : Optimum S 275N, 1,1 kW 400 V (revendeurs : source secondaire). η, cos φ : moteur de référence WEG W22 IE3 1,1 kW 4 pôles, carcasse 90S, catalogue WEG 50025712, p. 34 (In = 2,39 A) | À confirmer | Idem (§ 4.3.1, p. A23)
S1p | Scie à ruban — pompe d'arrosage | Optimum OPTIsaw S 275N | G2 | 1 | 400 | 0.09 | kWe |  | 1.000 | 0.09 | 0.09 | 0.75 | 0.07 | 0.1 | P : fiche Optimum S 275N (90 W). cos φ inconnu, pris égal à 1 (sous-estimation négligeable) | À confirmer | Idem (§ 4.3.1, p. A23)
K1 | Compresseur d'air à vis (étoile-triangle) | Atlas Copco G 11 | G2 | 1 | 400 | 11.00 | kWm | 0.912 | 0.830 | 14.53 | 14.53 | 1 | 14.53 | 21.0 | P = 11 kW : brochure Atlas Copco G 2-22 (2935 0869 42), p. 7. Démarrage étoile-triangle (version IEC) : manuel Atlas Copco G 7-G 15 (2924 7191 00), p. 58 et 80-81. η, cos φ : moteur de référence WEG W22 IE3 11 kW 2 pôles, catalogue WEG 50025712, p. 34 (In = 21,0 A). Polarité réelle à lire sur plaque | À confirmer | Au-dessus de la moyenne du § 4.3.1 : fonctionnement quasi continu pendant le poste ; 1 retenu par prudence
PR-L | Pont roulant 1 t — levage | Demag DC-Com 10, palan à chaîne 1 000 kg, mouflage 1/1 | G2 | 1 | 400 | 2.15 | kVA |  |  | 2.15 | 2.15 | 1 | 2.15 | 3.1 | Moteur ZNK 100 A 8/2, grande vitesse 1,10 kW, 40 % ED, In = 3,1 A à 380-415 V, cos φ 0,81 : Demag, Technical data DC-Com (203 571 44, 13/12/2019), p. 13 et 15. S = √3 × 400 × 3,1 | Sourcé | Moteur à pleine charge pendant le levage ; l'intermittence est prise en compte par le ks du groupe
PR-C | Pont roulant 1 t — translation chariot | Demag E11 (chariot U11) | G2 | 1 | 400 | 0.10 | kWe |  | 1.000 | 0.10 | 0.10 | 1 | 0.10 | 0.1 | Demag 203 571 44, p. 27 : E11, 0,1 / 0,025 kW. cos φ inconnu : S pris égal à P (sous-estimation négligeable) | À confirmer | Idem levage
PR-P | Pont roulant 1 t — translation pont | Demag E22-C (2, maître et esclave) | G2 | 2 | 400 | 0.20 | kWe |  | 1.000 | 0.20 | 0.40 | 1 | 0.40 | 0.3 | Hypothèse : 2 motoréducteurs E22-C, 0,2 / 0,05 kW, cités comme entraînement de translation (Demag 203 571 44, p. 28). À confirmer par devis de pont | À confirmer | Idem levage
E-AT | Éclairage atelier | Luminaires LED | G3 | 1 | 230 | 5.60 | kVA |  |  | 5.60 | 5.60 | 1 | 5.60 | 24.3 | Surface H5 × ratio fig. A9 (300 lx). ku = 1 : guide Schneider, p. A23 | Sourcé | Éclairage : ku = 1 (§ 4.3.1, p. A23)
E-MG | Éclairage magasin | Luminaires LED | G3 | 1 | 230 | 0.70 | kVA |  |  | 0.70 | 0.70 | 1 | 0.70 | 3.0 | Surface H5 × ratio fig. A9 (150 lx) | Sourcé | Idem
E-CP | Éclairage local compresseur | Luminaires LED | G3 | 1 | 230 | 0.14 | kVA |  |  | 0.14 | 0.14 | 1 | 0.14 | 0.6 | Surface H5 × ratio fig. A9 (150 lx) | Sourcé | Idem
E-BU | Éclairage bureaux | Luminaires LED | G3 | 1 | 230 | 1.44 | kVA |  |  | 1.44 | 1.44 | 1 | 1.44 | 6.3 | Surface H5 × ratio fig. A9 (500 lx) | Sourcé | Idem
E-LS | Éclairage locaux sociaux | Luminaires LED | G3 | 1 | 230 | 0.42 | kVA |  |  | 0.42 | 0.42 | 1 | 0.42 | 1.8 | Surface H5 × ratio fig. A9, ligne circulation (choix : pas de ligne spécifique) | Sourcé | Idem
PC1-5 | Coffret de prises (1 × 32 A tri + 2 × 16 A mono) | Coffrets industriels | G4 | 5 | 400 | 29.53 | kVA |  |  | 29.53 | 147.65 | 1 | 147.65 | — | Choix de conception (4 coffrets atelier, 1 magasin), méthode du courant assigné. ks du groupe : fig. A13 | Sourcé | Prises comptées à leur courant assigné (ku = 1) ; la faible utilisation est prise par ks = 0,2 (fig. A13, p. A26)
PB | Prises bureautiques | — | G5 | 1 | 230 | 1.50 | kVA |  |  | 1.50 | 1.50 | 1 | 1.50 | 6.5 | Surface bureaux × ratio fig. A9 « bureaux » (25 VA/m²) | Sourcé | Ratio de consommation déjà moyenné (fig. A9) : pas de réduction supplémentaire
CE | Chauffe-eau électrique 200 L | Atlantic Zénéo 200 L vertical mural | G5 | 1 | 230 | 2.20 | kWe |  | 1.000 | 2.20 | 2.20 | 1 | 2.20 | 9.6 | Fiche Atlantic Zénéo, réf. ED 999 538 (octobre 2015) : 2 200 W, 230 V. Résistif : cos φ = 1, ku = 1 (p. A23) | Sourcé | Résistif, chauffage : ku = 1 (§ 4.3.1, p. A23)
PAC | Pompe à chaleur air/air bureaux | Daikin Perfera FTXM50R + RXM50 | G5 | 1 | 230 | 1.45 | kWe |  | 1.000 | 1.45 | 1.45 | 1 | 1.45 | 6.3 | daikin.eu : capacité de chauffage nominale 5,8 kW, COP 4,00, d'où P = 5,8 ⁄ 4,00. Non dimensionnée par calcul thermique ; cos φ pris égal à 1. À confirmer : puissance absorbée maximale | À confirmer | Chauffage et climatisation : ku = 1 (§ 4.3.1 ; fig. A13)
TR | Auxiliaires des tubes radiants gaz | Jetto Monobloc JM 22 (22 kW gaz) | G5 | 4 | 230 | 0.07 | kWe |  | 1.000 | 0.07 | 0.26 | 1 | 0.26 | 0.3 | Fiche Jetto Monobloc (Batiproduits) : 65 W, 230 V. Nombre de tubes provisoire (4) : calcul de déperditions au J6. Impact négligeable | À confirmer | Auxiliaires en service pendant toute la chauffe : ku = 1
 | Total puissance installée |  |  |  |  |  |  |  |  |  | 290.91 |  | 262.82

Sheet: Synthese
DEBT_01 — Bilan de puissance — Synthèse par groupe et au TGBT
Pu = ks × Σ(ku × S) ; IB = Pu ⁄ (√3 × U) (guide Schneider 2017, § 4.3 à 4.4, p. A23 à A26)
Groupe | Contenu | Σ ku × S (kVA) | ks | Source du ks | P utilisation (kVA) | IB (A)
G1 | Machines à commande numérique (4 circuits) | 80.56 | 0.8 | Fig. A12, p. A25 : tableau de 4 à 5 circuits | 64.45 | 93.0
G2 | Autres moteurs : perceuse, scie, compresseur, pont roulant (4 circuits) | 20.89 | 0.8 | Fig. A12, p. A25 : tableau de 4 à 5 circuits | 16.71 | 24.1
G3 | Éclairage | 8.30 | 1 | Fig. A13, p. A26 : éclairage | 8.30 | 12.0
G4 | Coffrets de prises | 147.65 | 0.2 | Fig. A13, p. A26 : prises 0,1 à 0,2, valeur haute (usage industriel) | 29.53 | 42.6
G5 | Bureaux, locaux sociaux, chauffage : bureautique, chauffe-eau, pompe à chaleur, auxiliaires | 5.41 | 1 | Fig. A13, p. A26 : chauffage et conditionnement d'air ; valeur prudente pour la bureautique | 5.41 | 7.8
 | Au TGBT
 | Somme des puissances d'utilisation des groupes | 124.40 | kVA
 | ks du TGBT (provisoire, recalculé au J3 avec l'architecture) | 0.90 | —
 | Puissance d'utilisation au TGBT (coefficient d'extension compris) | 111.96 | kVA
 | Courant d'emploi au point de livraison | 161.6 | A
 | Plafond du raccordement C4 | 250 | kVA
 | Marge par rapport au plafond | 55.2% | —
 | Vérification | Sous le plafond C4 | —
 | Puissance installée totale (rappel) | 290.91 | kVA
 | Rapport puissance d'utilisation ⁄ puissance installée | 38.5% | —
 | Contrôle : force motrice d'un atelier d'usinage par ratio (fig. A9, 300 VA/m²) | 120.0 | kVA
 | Contrôle : S installée des seules machines CN (groupe G1) | 107.42 | kVA
 | Coefficient d'extension (H13 : aucune extension prévue) | 1.00 | —
 | Guide Schneider 2017, § 4.3 (p. A22) et § 4.5 (p. A26) : prise en compte des extensions prévisibles. H13 : coefficient 1 ; la marge sous le plafond C4 couvrirait une extension modérée.

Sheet: Souscription
DEBT_01 — Puissance à souscrire (TURPE 7, BT > 36 kVA)
Formules : Enedis, TURPE 7 HTA/BT, tarifs au 1er août 2026, p. 15-16 ; coefficients : délibération CRE n° 2026-105, annexe 2, p. 21 à 28
Donnée | Valeur | Unité |  | Source / justification
Puissance d'utilisation au TGBT | 111.96 | kVA |  | Bilan, onglet Synthèse
Puissance souscrite retenue, identique sur les 4 plages | 112.00 | kVA |  | Souscription par multiples de 1 kVA (Enedis, p. 15). Pic en heures pleines toute l'année ; la règle P1 ≤ P2 ≤ P3 ≤ P4 (plage 1 = heures pleines de saison haute) impose alors la même valeur partout
CMDPS : coefficient α | 12.79 | €/h |  | CRE 2026-105, p. 28 ; CMDPS = α × h, h : durée de dépassement (Enedis, p. 16)
Composante de gestion (contrat unique, Rf inclus) | 222.53 | €/an |  | CRE 2026-105, p. 21
Composante de comptage | 291.88 | €/an |  | CRE 2026-105, annexe 2
Hypothèse H12 : fonctionnement (majorant d'énergie)
Donnée | Valeur | Unité |  | Justification
Heures de fonctionnement par jour | 8 | h |  | Un poste de journée (H3) ; hypothèse
Jours par semaine | 5 | j |  | H3
Semaines par an | 52 | sem |  | Majorant : aucun congé déduit
Heures de fonctionnement par an | 2080 | h |  | Calcul
Part de l'année en saison haute (novembre à mars) | 0.417 | — |  | Enedis, glossaire, p. 22
Énergie annuelle majorante | 232883.9979 | kWh |  | Majorant : puissance d'utilisation maintenue tout le poste, kVA pris pour des kW
dont heures pleines de saison haute | 97034.99914 | kWh |  | Toute l'énergie supposée en heures pleines : cas le plus favorable à la longue utilisation
dont heures pleines de saison basse | 135848.9988 | kWh |  | Idem
Comparaison courte utilisation ⁄ longue utilisation
Terme | Courte util. | Longue util. | Unité | Source
b1 : heures pleines de saison haute | 18.15 | 31.08 | €/kVA/an | CRE 2026-105, p. 27
c1 : heures pleines de saison haute | 7.12 | 5.86 | c€/kWh | Idem
c3 : heures pleines de saison basse | 2.19 | 2.07 | c€/kWh | Idem
Part puissance : b1 × PS | 2032.80 | 3480.96 | €/an | CS = b1·P1 + Σ bi·(Pi − Pi−1) + Σ ci·Ei ; Pi toutes égales, donc seul b1·P1 subsiste
Part énergie : c1 × E1 + c3 × E3 | 9883.99 | 8498.33 | €/an | Énergies majorantes (H12)
Composante de soutirage totale | 11916.79 | 11979.29 | €/an | Somme
Écart longue − courte utilisation |  | 62.50 | €/an | Positif : la courte utilisation est moins chère, même dans le cas majorant
Conclusion
Option retenue : courte utilisation, 112 kVA sur les quatre plages. Elle reste la moins chère même avec l'énergie majorante de H12 ; l'énergie réelle, plus faible, renforce ce choix.
Ordre de grandeur : 1 kVA souscrit en plus coûte b1 = 18,15 €/an ; 1 heure de dépassement coûte α = 12,79 €. Une marge de souscription est donc peu coûteuse face au risque de dépassement.

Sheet: Parametres
DEBT_01 — Bilan de puissance — Paramètres
Version 4 (clôture du J2) — texte bleu : donnée saisie ; texte noir : formule
Paramètre | Valeur | Unité | Source / justification
Tension entre phases U | 400 | V | Cahier des charges v1.0, section 3 (réseau triphasé 230/400 V)
Tension simple V | 230 | V | Idem
Racine de 3 | 1.7321 | — | Constante
Plafond de puissance du raccordement C4 | 250 | kVA | Cahier des charges v1.0, section 3 (segment C4, 36 à 250 kVA)
Surfaces (H5, provisoires jusqu'au plan du J3)
Zone | Surface | Unité | Source / justification
Atelier | 400 | m² | Valeur de programme (H5)
Magasin et expédition | 100 | m² | Valeur de programme (H5)
Local compresseur | 20 | m² | Valeur de programme (H5)
Bureaux (m² utiles) | 60 | m² | INRS ED 23 (2007) : 10 m² par poste × 6 postes (H3, H5)
Locaux sociaux | 60 | m² | Valeur de programme (H5)
Ratios d'éclairage (H11) et de bureautique
Usage | Ratio | Unité | Source / justification
Éclairage — circulation, stockage (150 lx) | 7 | VA/m² | Guide Schneider 2017, fig. A9, p. A22-A23 (base fluorescente : majorant pour LED)
Éclairage — gros travaux, atelier (300 lx) | 14 | VA/m² | Idem
Éclairage — bureaux (500 lx) | 24 | VA/m² | Idem
Force motrice — bureaux (bureautique) | 25 | VA/m² | Guide Schneider 2017, fig. A9, p. A23
Contrôle : force motrice atelier d'usinage | 300 | VA/m² | Guide Schneider 2017, fig. A9, p. A23 (ordre de grandeur de contrôle)
Coffret de prises type (choix de conception, J2.5)
Élément | Valeur | Unité | Source / justification
Prise industrielle triphasée : courant assigné | 32 | A | Choix de conception : 1 par coffret
Prises monophasées : courant assigné | 16 | A | Choix de conception
Nombre de prises monophasées par coffret | 2 | — | Choix de conception
Puissance d'un coffret (méthode du courant assigné) | 29.53 | kVA | S = (√3 × U × 32 + 2 × V × 16) ⁄ 1000
Justification du nombre et de la composition des coffrets
Point | Valeur | Unité | Justification
Nombre de coffrets dans l'atelier | 4 | — | Un coffret par zone de travail : tournage, fraisage, débit et perçage, établi et contrôle ; chaque poste à portée d'un câble d'outillage portatif, sans rallonge au sol entre les machines. Aucune norme ne fixe ce nombre en local industriel : choix de conception, à vérifier sur le plan du J3
Nombre de coffrets dans le magasin | 1 | — | Outillage de réception et d'expédition. Choix de conception, à vérifier sur le plan du J3
Calibres retenus (16 A et 32 A) |  | — | Calibres normalisés des prises industrielles (norme CEI 60309) ; 32 A triphasé pour un équipement mobile puissant (poste à souder), 16 A pour l'outillage portatif et les baladeuses
Méthode de comptage |  | — | Chaque prise comptée à son courant assigné (ku = 1) ; la faible utilisation réelle est prise en compte par ks = 0,2 sur le groupe (fig. A13, p. A26)
Poids sur le bilan |  | — | Environ 30 kVA d'utilisation, 2e poste du bilan : levier à discuter au J3 avec le plan

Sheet: Registre
DEBT_01 — Registre des sources à confirmer
À vider avant la version finale du dossier
N° | Élément | Valeur provisoire | Source actuelle | Source à obtenir | Poids sur le bilan
1 | Scie : fiche constructeur | 1,1 kW ; pompe 90 W | Revendeurs Optimum (secondaire) | Fiche ou notice Optimum / Stürmer S 275N (réf. 3300260) | Négligeable
2 | Compresseur : polarité et courant du moteur | 2 pôles supposés ; 21,0 A (moteur de référence) | WEG W22 IE3 11 kW 2 p. (primaire, moteur de référence) | Plaque signalétique ou fiche électrique Atlas Copco G 11 | Modéré (≈ 14 kVA)
3 | Pont roulant : translation du pont | 2 × 0,2 kW | Demag 203 571 44, p. 28 (usage hors palan) | Devis d'un pont monopoutre 1 t | Négligeable
4 | Pont roulant : hauteur de poutre, chemin de roulement, jeu en partie haute | à déterminer | — | Devis constructeur ; norme EN 15011 (payante) | Conditionne la hauteur sous charpente (H4)
5 | Pompe à chaleur : puissance absorbée maximale | 1,45 kW (nominale) ; fusible maxi 16 A | daikin.eu ; fiche RXM-R (EEDEN21A), p. 5-6 | Pages FTXM50R du databook Daikin | Faible
6 | Tubes radiants : nombre | 4 × 65 W | Notice Jetto JM 12 / JM 22 (19/07/2010), p. 2, 6, 7 | Calcul de déperditions (J6) | Négligeable
7 | Tubes radiants : tension neutre-terre | aucune tension admise (notice Jetto) | Notice Jetto, p. 7 | Vérification en schéma TT au J4 ; transformateur de séparation éventuel | Point de protection, pas de puissance
8 | Chauffe-eau : fiche chiffrée | 2 200 W | Revendeurs (secondaire) | Fiche Atlantic Zénéo en vigueur | Négligeable
9 | Coffrets de prises : nombre et composition | 5 coffrets (1 × 32 A tri + 2 × 16 A) | Choix de conception (onglet Paramètres) | Vérification sur le plan AutoCAD (J3) | Fort (≈ 30 kVA d'utilisation)
10 | ks du TGBT | 0,9 (3 départs supposés) | Fig. A12, hypothèse d'architecture | Architecture de distribution (J3) | Modéré (≈ 12 kVA)
11 | TURPE : puissance souscrite minimale et maximale, heures creuses | — | Brochure Enedis au 01/08/2026 (souscription par multiples de 1 kVA) | Délibération CRE 2025-78, § 5.1, p. 140-146 | Faible sur le choix

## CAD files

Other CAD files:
03_PlanImplantation/DEBT_03_PlanImplantation_v1.dwg

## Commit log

2026-09-21 Initialisation de l'arborescence des livrables
    - Neuf dossiers de livrables (00 à 08), rendus visibles par des fichiers .gitkeep
    - README réécrit : objet, nature fictive de l'étude, livrables, jalons
    - SOURCES.md : référentiel documentaire, titres vérifiés sur les pages de garde
    - .gitignore : fichiers temporaires Office, AutoCAD et Windows
2026-09-22 Correction du formatage Markdown du README
    Symboles Markdown échappés par le Bloc-notes (\#, \_) : fichier réenregistré en texte brut depuis Antigravity. Ajout du retour à la ligne final du .gitignore.
2026-09-22 Jalon J1 : cahier des charges v1.0
    Hypothèses de base H1 à H5, H7 et H8 validées. README et SOURCES.md mis à jour.
2026-09-26 Jalon J2 : bilan de puissance et cahier des charges v1.1
    Bilan v4 : puissance d'utilisation 112,0 kVA, souscription 112 kVA en courte utilisation. Hypothèses H11 à H13. Sources complétées.
    [DEBT_01_BilanPuissance_v4.xlsx]
2026-09-26 Bilan de puissance v4 : version PDF de lecture
2026-10-03 J3.6 phase 1-3 : calques, enveloppe et cloisons du plan d'implantation
    [DEBT_03_PlanImplantation_v1.dwg]
2026-10-04 J3.6 phase 5 : implantation de l'atelier, aperçu PNG
    H16 bis ; atelier porté à 17,59 m (zone copeaux intégrée)
    [DEBT_03_PlanImplantation_v1.dwg]
2026-10-04 J3.6 phase 5 : magasin et compresseur
    Magasin porté à 5,00 m (14 emplacements, H23) ; affectation des emplacements H34 ; bâtiment 41,46 m
    [DEBT_03_PlanImplantation_v1.dwg]
